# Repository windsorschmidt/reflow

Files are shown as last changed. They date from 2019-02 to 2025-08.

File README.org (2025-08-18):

* Reflow Oven Controller

"Yeah man, but it's a *dry* heat!." —PFC William L. Hudson

* About

Hardware and firmware sources for a 2-channel reflow (toaster) oven
controller.

In spite of great alternatives such as [[http://www.whizoo.com/controleo3][Controleo3]], I decided to build
my own controller for personal use. The design is intended to be
simple and self-contained. Comments and pull requests are welcome!

Some pictures of the assembled controller and completed oven retrofit
[[https://imgur.com/gallery/L4Zu2G3][are online here]].

[[reflow.png?raw=true]]

* Hardware Features

- Two triac-controlled power outputs (no external SSRs needed)
- AC line zero-crossing detection for reduced switching noise
- Temperature sensor using MAX31855 K-type thermocouple amplifier
- Compact user interface with OLED display and Cherry MX key-switches
- Data-logging output though USB and serial-to-Bluetooth module
- Tone transducer for audible alerts (e.g. reflow cycle complete)
- Mounts in a dedicated enclosure for simple wiring using IEC connectors
- [[https://en.wikipedia.org/wiki/Aliens_(film)][Aliens]] film inspired aesthetics

* Firmware Features

- Non-profiling PID routine controls triac outputs to track the active reflow profile
- Reflow profile can be viewed & edited at run-time (currently no ability to save edits)
  
[[ui.png?raw=true]]

* References

- [[https://www.allaboutcircuits.com/projects/controlling-ac-mains-with-a-microcontroller-for-fun-and-profit][This project]] was used as a basis for the triac control and zero-crossing detection circuitry
- [[https://www.reddit.com/user/rich-creamery-butter][This Reddit user]] provided [[https://imgur.com/a/sCKgO][Assembly pics]] used as a guide when converting my own oven
- The excellent [[https://github.com/olikraus/u8g2][u8g2]] library used to render user-interface graphics and text
- [[mailto:p@yusukekamiyamane.com][Yusuke Kamiyamane's]] Tempesta Seven font used in the gnuplot script
- [[http://kicad-pcb.org][KiCad]] EDA suite used for hardware schematic capture and PCB layout

* Disclaimer

This information is supplied "as is" and without warranties of any
kind, express, implied, or statutory including, but not limited to,
any implied warranty of merchantability, noninfringement or fitness
for a particular purpose and no responsibility is assumed by the
author for its use, nor for any infringements of patents or other
rights of third parties that may result from its use.

In no event will the author be liable for any loss or damage including
without limitation, indirect or consequential loss or damage, or any
loss or damage whatsoever arising from or in connection with the use
of this information.

* License

[[LICENSE.txt][MIT license]]

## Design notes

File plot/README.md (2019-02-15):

# About

The included script can be used to plot data stored in a file, as sent by the controller. Data are stored line-wise as JSON strings.

## Requirements:

- gnuplot - http://www.gnuplot.info/
- jq - https://stedolan.github.io/jq/

## Plotting

Run the script, passing the name of a log file as the argument (an example file is included):

```
$ sh make_plot.sh reflow_example.log
```

You may get a warning from gnuplot about plotting with an 'unknown' terminal -- this can be ignored. The resulting plots (with light and dark background) are generated in the current directory.

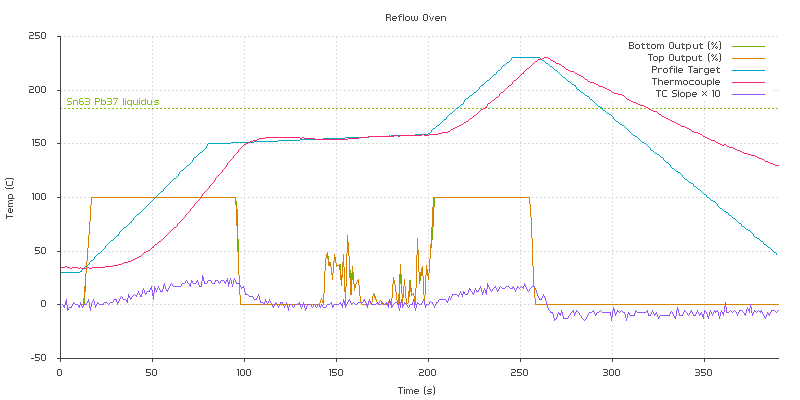
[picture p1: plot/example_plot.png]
Plot of data logged by the controller


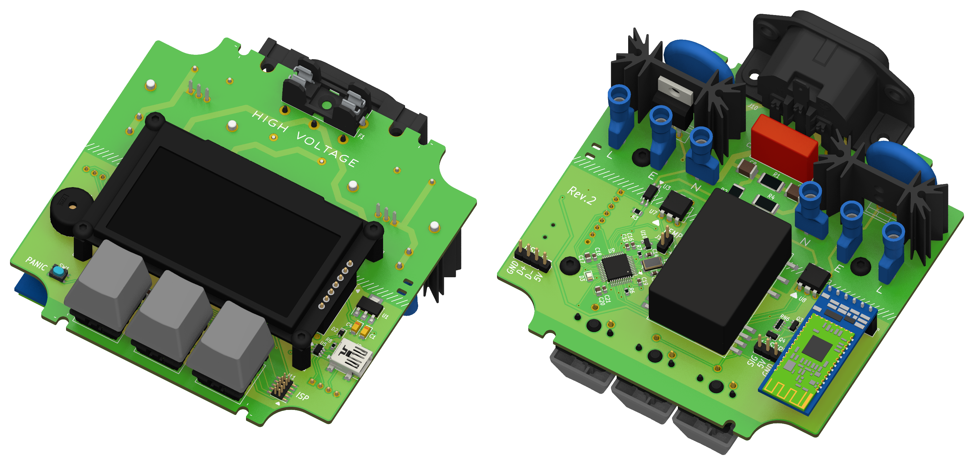
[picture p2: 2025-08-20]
reflow.png

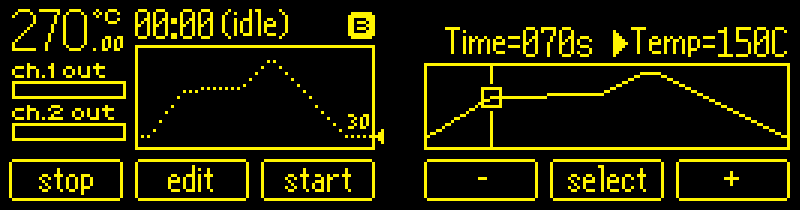
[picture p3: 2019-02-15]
ui.png

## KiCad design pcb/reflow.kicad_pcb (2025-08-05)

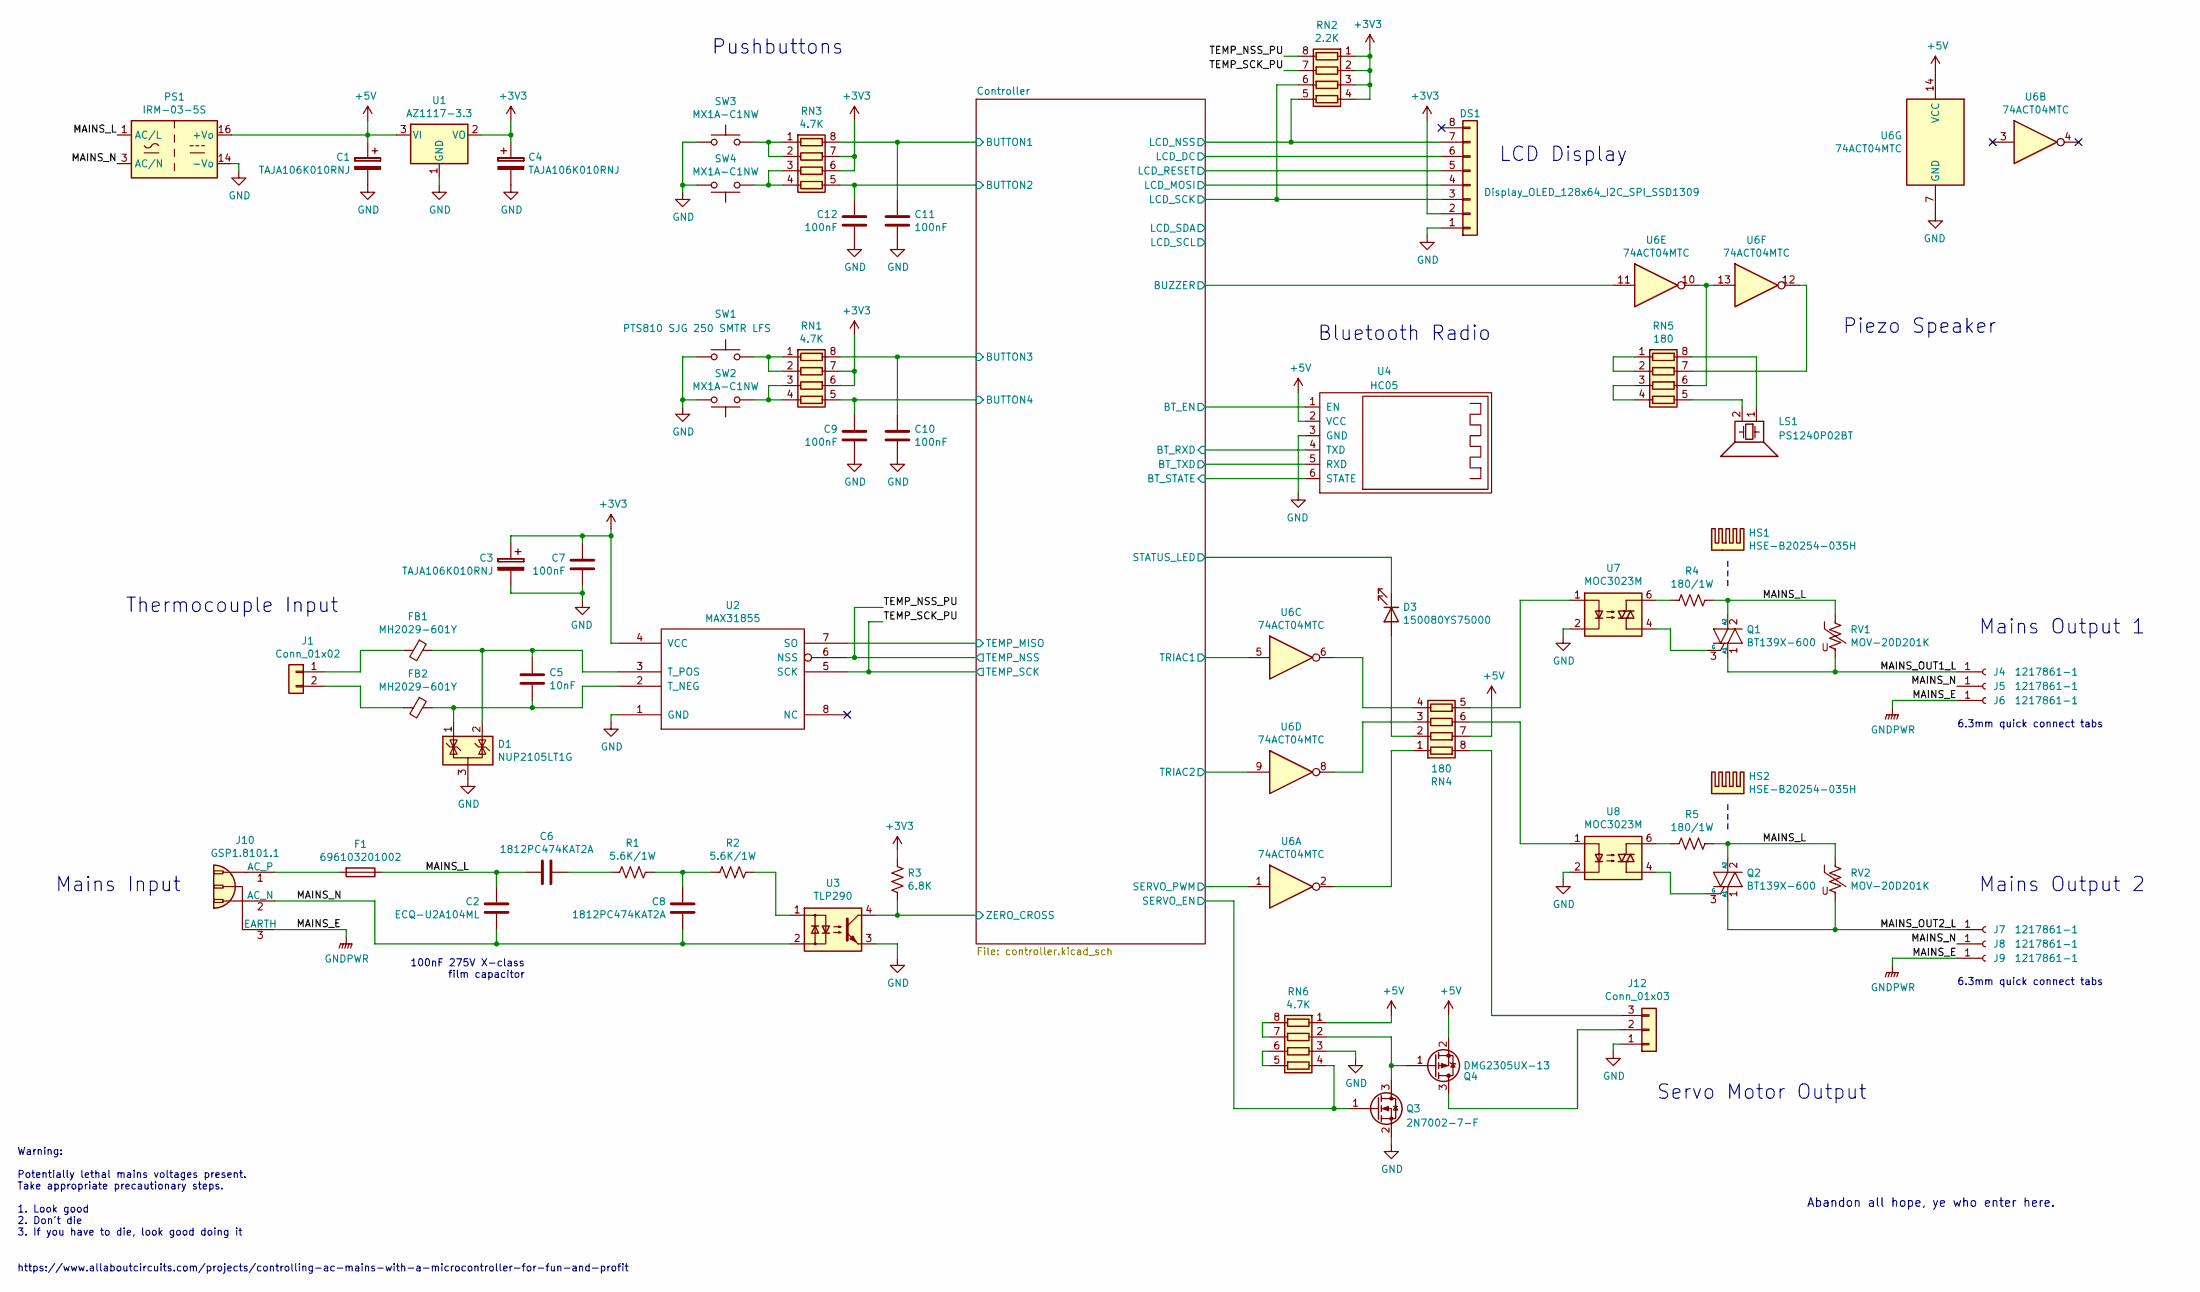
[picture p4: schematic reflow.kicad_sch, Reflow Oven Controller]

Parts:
C1, C3, C4: TAJA106K010RNJ; CP_EIA-3216-18_Kemet-A
C2: ECQ-U2A104ML; C_Rect_L18.0mm_W6.0mm_P15.00mm_FKS3_FKP3
C5: 10nF; C_0805_2012Metric
C6, C8: 1812PC474KAT2A; C_1812_4532Metric
C7, C9, C10, C11, C12: 100nF; C_0805_2012Metric
D1: NUP2105LT1G; SOT-23
D3: 150080YS75000; LED_0805_2012Metric
DS1: Display_OLED_128x64_I2C_SPI_SSD1309
F1: 696103201002; Fuseholder_Cylinder-5x20mm_Stelvio-Kontek_PTF78_Horizontal_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
FB1, FB2: MH2029-601Y; L_0805_2012Metric
HS1, HS2: HSE-B20254-035H; Heatsink_CUI_HSE-B20254-035H
J1: Conn_01x02; PinHeader_1x02_P2.54mm_Vertical
J4, J5, J6, J7, J8, J9: 1217861-1; Connector_FastOn_6.35mm
J10: GSP1.8101.1; Connector_Schurter_GSP1.8101.1
J12: Conn_01x03; PinHeader_1x03_P2.54mm_Vertical
LS1: PS1240P02BT; Buzzer_TDK_PS1240P02BT
PS1: IRM-03-5S; Converter_ACDC_MeanWell_IRM-03-xx_SMD
Q1, Q2: BT139X-600; TO-220-3_Vertical
Q3: 2N7002-7-F; SOT-23
Q4: DMG2305UX-13; SOT-23
R1, R2: 5.6K/1W; R_2512_6332Metric
R3: 6.8K; R_0805_2012Metric
R4, R5: 180/1W; R_2512_6332Metric
RN1, RN3, RN6: 4.7K; R_Array_Convex_4x0603
RN2: 2.2K; R_Array_Convex_4x0603
RN4, RN5: 180; R_Array_Convex_4x0603
RV1, RV2: MOV-20D201K; RV_Disc_D21.5mm_W4.3mm_P10mm
SW1: PTS810 SJG 250 SMTR LFS; Pushbutton_PTS810_SJx_250_SMTR_LFS
SW2, SW3, SW4: MX1A-C1NW; Switch_Cherry_MX1A_1.00u_PCB
U1: AZ1117-3.3; SOT-223
U2: MAX31855; SOIC-8_3.9x4.9mm_P1.27mm
U3: TLP290; SOP-4_4.4x2.8mm_P1.27mm
U4: HC05; Module_Bluetooth_HC05
U6: 74ACT04MTC; TSSOP-14_4.4x5mm_P0.65mm
U7, U8: MOC3023M; DIP-6_W7.62mm

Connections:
+3V3: C3.1, C4.1, C7.1, DS1.2, R3.2, RN1.6 (R3.2), RN1.7 (R2.2), RN2.1 (R1.1), RN2.2 (R2.1), RN2.3 (R3.1), RN2.4 (R4.1), RN3.6 (R3.2), RN3.7 (R2.2), U1.2 (VO), U2.4 (VCC); also elsewhere on the board
+5V: C1.1, PS1.16 (+Vo), Q4.2 (S), RN4.7 (R2.2), RN6.1 (R1.1), U1.3 (VI), U4.2 (VCC), U6.14 (VCC); also elsewhere on the board
/Controller/BT_EN: U4.1 (EN); also elsewhere on the board
/Controller/BT_RXD: U4.4 (TXD); also elsewhere on the board
/Controller/BT_STATE: U4.6 (STATE); also elsewhere on the board
/Controller/BT_TXD: U4.5 (RXD); also elsewhere on the board
/Controller/BUTTON1: C11.1, RN3.8 (R1.2); also elsewhere on the board
/Controller/BUTTON2: C12.2, RN3.5 (R4.2); also elsewhere on the board
/Controller/BUTTON3: C10.1, RN1.8 (R1.2); also elsewhere on the board
/Controller/BUTTON4: C9.2, RN1.5 (R4.2); also elsewhere on the board
/Controller/BUZZER: U6.11; also elsewhere on the board
/Controller/LCD_DC: DS1.6; also elsewhere on the board
/Controller/LCD_MOSI: DS1.4; also elsewhere on the board
/Controller/LCD_NSS: DS1.7, RN2.5 (R4.2); also elsewhere on the board
/Controller/LCD_RESET: DS1.5; also elsewhere on the board
/Controller/LCD_SCK: DS1.3, RN2.6 (R3.2); also elsewhere on the board
/Controller/SERVO_EN: Q3.1 (G), RN6.4 (R4.1); also elsewhere on the board
/Controller/SERVO_PWM: U6.1; also elsewhere on the board
/Controller/STATUS_LED: D3.1 (K); also elsewhere on the board
/Controller/TEMP_MISO: U2.7 (SO); also elsewhere on the board
/Controller/TRIAC1: U6.5; also elsewhere on the board
/Controller/TRIAC2: U6.9; also elsewhere on the board
/Controller/ZERO_CROSS: R3.1, U3.4; also elsewhere on the board
/MAINS_L: C2.1, C6.2, F1.1, PS1.1 (AC/L), Q1.2 (A2), Q2.2 (A2), R4.1, R5.1, RV1.1, RV2.1
/MAINS_N: C2.2, C8.1, J5.1, J8.1, J10.2 (AC_N), PS1.3 (AC/N), U3.2
/MAINS_OUT1_L: J4.1, Q1.1 (A1), RV1.2
/MAINS_OUT2_L: J7.1, Q2.1 (A1), RV2.2
/TEMP_NSS_PU: RN2.8 (R1.2), U2.6 (NSS); also elsewhere on the board
/TEMP_SCK_PU: RN2.7 (R2.2), U2.5 (SCK); also elsewhere on the board
GND: C1.2, C3.2, C4.2, C7.2, C9.1, C10.2, C11.2, C12.1, D1.3 (A), DS1.1, J12.1, PS1.14 (-Vo), Q3.2 (S), RN6.3 (R3.1), SW1.1, SW2.1, SW3.1, SW4.1, U1.1 (GND), U2.1 (GND), U3.3, U4.3 (GND), U6.7 (GND), U7.2, U8.2; also elsewhere on the board
GNDPWR: J6.1, J9.1, J10.3 (EARTH)
unnamed: C5.1, D1.2 (K), FB1.1, U2.3 (T_POS)
unnamed: C5.2, D1.1 (K), FB2.1, U2.2 (T_NEG)
unnamed: C6.1, R1.2
unnamed: C8.2, R1.1, R2.2
unnamed: D3.2 (A), RN4.2 (R2.1)
unnamed: F1.2, J10.1 (AC_P)
unnamed: FB1.2, J1.1
unnamed: FB2.2, J1.2
unnamed: J12.2, Q4.3 (D)
unnamed: J12.3, RN4.8 (R1.2)
unnamed: LS1.1, RN5.8 (R1.2)
unnamed: LS1.2, RN5.5 (R4.2)
unnamed: Q1.3 (G), U7.4
unnamed: Q2.3 (G), U8.4
unnamed: Q3.3 (D), Q4.1 (G), RN6.2 (R2.1)
unnamed: R2.1, U3.1
unnamed: R4.2, U7.6
unnamed: R5.2, U8.6
unnamed: RN1.1 (R1.1), RN1.2 (R2.1), SW1.2
unnamed: RN1.3 (R3.1), RN1.4 (R4.1), SW2.2
unnamed: RN3.1 (R1.1), RN3.2 (R2.1), SW3.2
unnamed: RN3.3 (R3.1), RN3.4 (R4.1), SW4.2
unnamed: RN4.1 (R1.1), U6.2
unnamed: RN4.3 (R3.1), U6.8
unnamed: RN4.4 (R4.1), U6.6
unnamed: RN4.5 (R4.2), U7.1
unnamed: RN4.6 (R3.2), U8.1
unnamed: RN5.1 (R1.1), RN5.2 (R2.1)
unnamed: RN5.3 (R3.1), RN5.4 (R4.1)
unnamed: RN5.6 (R3.2), U6.10, U6.13
unnamed: RN5.7 (R2.2), U6.12
unnamed: RN6.5 (R4.2), RN6.6 (R3.2)
unnamed: RN6.7 (R2.2), RN6.8 (R1.2)

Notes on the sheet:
6.3mm quick connect tabs
Pushbuttons
Bluetooth Radio
Mains Input
Abandon all hope, ye who enter here.
Mains Output 2
100nF 275V X-class film capacitor
Thermocouple Input
https://www.allaboutcircuits.com/projects/controlling-ac-mains-with-a-microcontroller-for-fun-and-profit
LCD Display
Warning: Potentially lethal mains voltages present. Take appropriate precautionary steps. 1. Look good 2. Don't die 3. If you have to die, look good doing it
Mains Output 1
Servo Motor Output
Piezo Speaker

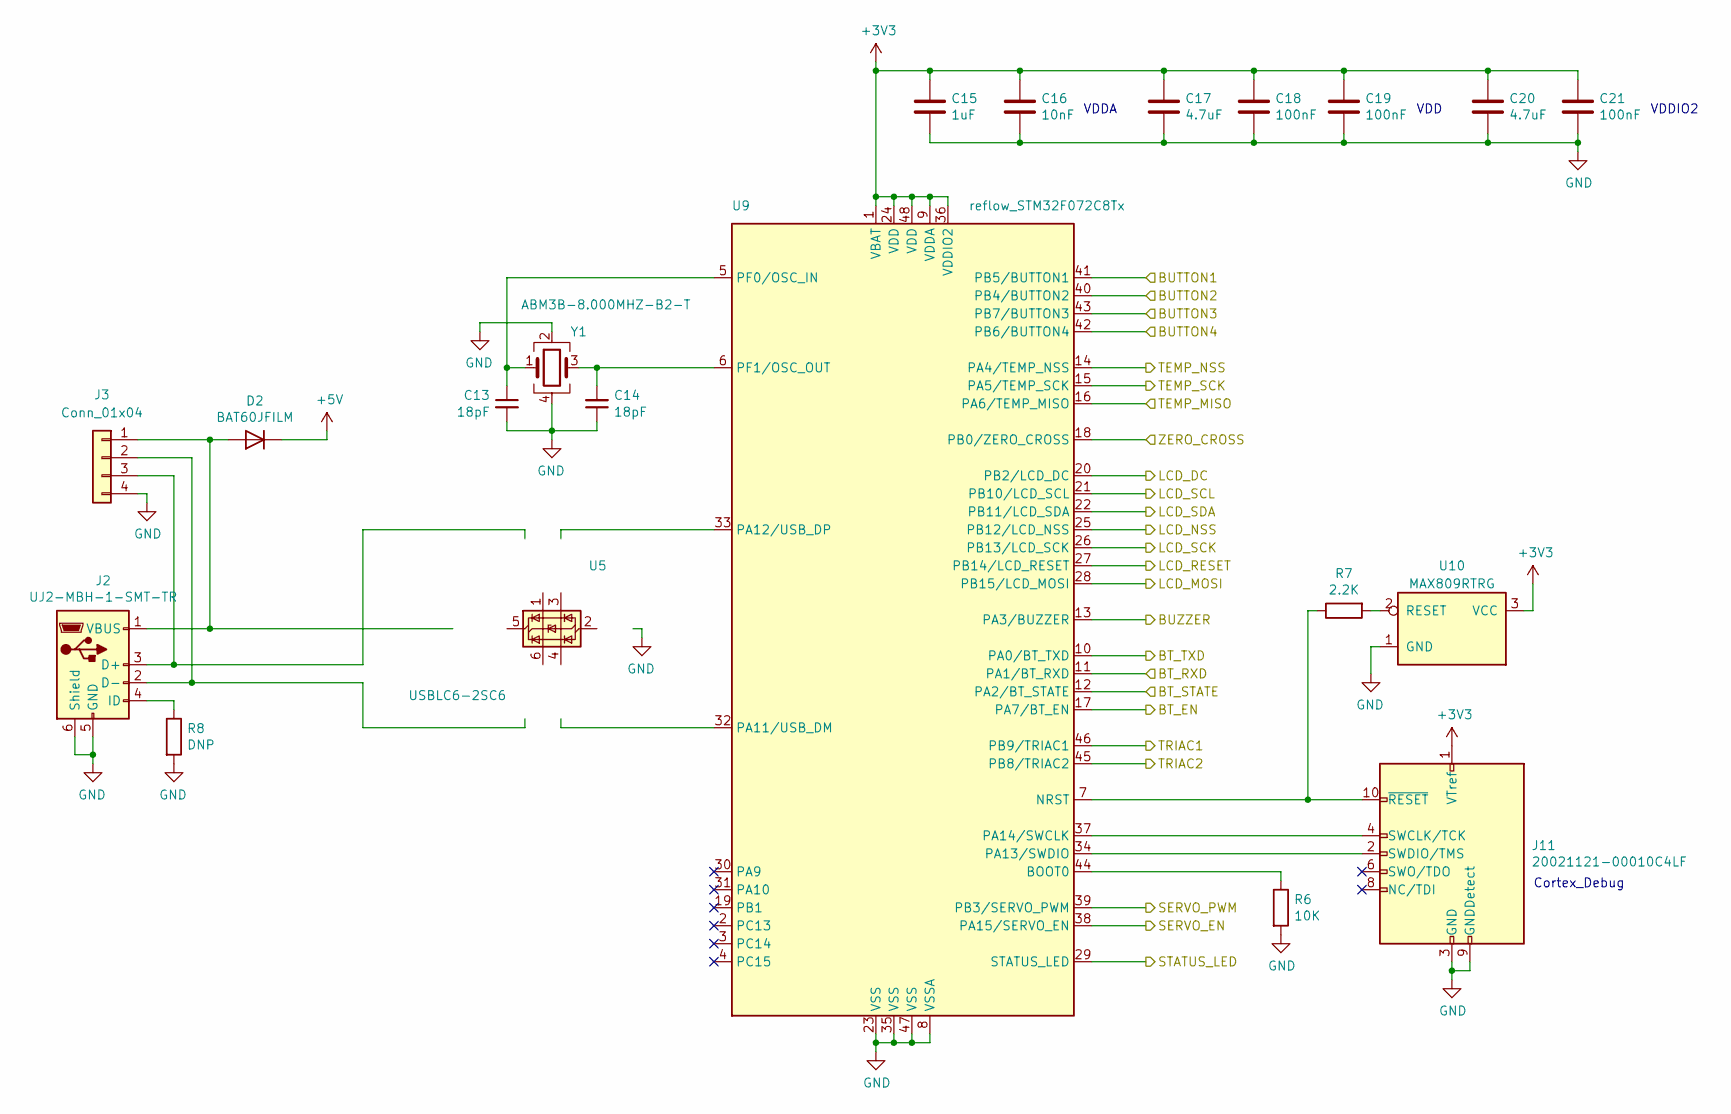
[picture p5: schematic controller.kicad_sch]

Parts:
C13, C14: 18pF; C_0603_1608Metric
C15: 1uF; C_0603_1608Metric
C16: 10nF; C_0603_1608Metric
C17, C20: 4.7uF; C_0805_2012Metric
C18, C19, C21: 100nF; C_0603_1608Metric
D2: BAT60JFILM; D_SOD-323
J2: UJ2-MBH-1-SMT-TR; USB_Mini-B_Lumberg_2486_01_Horizontal
J3: Conn_01x04; PinHeader_1x04_P2.54mm_Vertical
J11: 20021121-00010C4LF; PinHeader_2x05_P1.27mm_Vertical_SMD
R6: 10K; R_0603_1608Metric
R7: 2.2K; R_0603_1608Metric
R8: DNP; R_0603_1608Metric
U5: USBLC6-2SC6; SOT-23-6
U9: reflow_STM32F072C8Tx; LQFP-48_7x7mm_P0.5mm
U10: MAX809RTRG; SOT-23
Y1: ABM3B-8.000MHZ-B2-T; Crystal_Abracon_ABM3B-8.000MHZ-B2-T

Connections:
+3V3: C15.1, C16.2, C17.2, C18.1, C19.1, C20.2, C21.1, J11.1 (VTref), U9.1 (VBAT), U9.9 (VDDA), U9.24 (VDD), U9.36 (VDDIO2), U9.48 (VDD), U10.3 (VCC); also elsewhere on the board
+5V: D2.1 (K); also elsewhere on the board
/Controller/BT_EN: U9.17 (PA7/BT_EN); also elsewhere on the board
/Controller/BT_RXD: U9.11 (PA1/BT_RXD); also elsewhere on the board
/Controller/BT_STATE: U9.12 (PA2/BT_STATE); also elsewhere on the board
/Controller/BT_TXD: U9.10 (PA0/BT_TXD); also elsewhere on the board
/Controller/BUTTON1: U9.41 (PB5/BUTTON1); also elsewhere on the board
/Controller/BUTTON2: U9.40 (PB4/BUTTON2); also elsewhere on the board
/Controller/BUTTON3: U9.43 (PB7/BUTTON3); also elsewhere on the board
/Controller/BUTTON4: U9.42 (PB6/BUTTON4); also elsewhere on the board
/Controller/BUZZER: U9.13 (PA3/BUZZER); also elsewhere on the board
/Controller/LCD_DC: U9.20 (PB2/LCD_DC); also elsewhere on the board
/Controller/LCD_MOSI: U9.28 (PB15/LCD_MOSI); also elsewhere on the board
/Controller/LCD_NSS: U9.25 (PB12/LCD_NSS); also elsewhere on the board
/Controller/LCD_RESET: U9.27 (PB14/LCD_RESET); also elsewhere on the board
/Controller/LCD_SCK: U9.26 (PB13/LCD_SCK); also elsewhere on the board
/Controller/SERVO_EN: U9.38 (PA15/SERVO_EN); also elsewhere on the board
/Controller/SERVO_PWM: U9.39 (PB3/SERVO_PWM); also elsewhere on the board
/Controller/STATUS_LED: U9.29 (STATUS_LED); also elsewhere on the board
/Controller/TEMP_MISO: U9.16 (PA6/TEMP_MISO); also elsewhere on the board
/Controller/TRIAC1: U9.46 (PB9/TRIAC1); also elsewhere on the board
/Controller/TRIAC2: U9.45 (PB8/TRIAC2); also elsewhere on the board
/Controller/ZERO_CROSS: U9.18 (PB0/ZERO_CROSS); also elsewhere on the board
/TEMP_NSS_PU: U9.14 (PA4/TEMP_NSS); also elsewhere on the board
/TEMP_SCK_PU: U9.15 (PA5/TEMP_SCK); also elsewhere on the board
GND: C13.2, C14.1, C15.2, C16.1, C17.1, C18.2, C19.2, C20.1, C21.2, J2.5 (GND), J2.6 (Shield), J3.4, J11.3 (GND), J11.5 (GND), J11.9 (GNDDetect), R6.2, R8.2, U5.2 (GND), U9.8 (VSSA), U9.23 (VSS), U9.35 (VSS), U9.47 (VSS), U10.1 (GND), Y1.2, Y1.4; also elsewhere on the board
unnamed: C13.1, U9.5 (PF0/OSC_IN), Y1.1
unnamed: C14.2, U9.6 (PF1/OSC_OUT), Y1.3
unnamed: J2.4 (ID), R8.1
unnamed: J11.2 (SWDIO/TMS), U9.34 (PA13/SWDIO)
unnamed: J11.4 (SWCLK/TCK), U9.37 (PA14/SWCLK)
unnamed: J11.10 (~RESET), R7.1, U9.7 (NRST)
unnamed: R6.1, U9.44 (BOOT0)
unnamed: R7.2, U10.2 (RESET)
unnamed: U5.1 (I/O1), U9.33 (PA12/USB_DP)
unnamed: U5.3 (I/O2), U9.32 (PA11/USB_DM)

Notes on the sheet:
VDDIO2
VDD
VDDA
Cortex_Debug

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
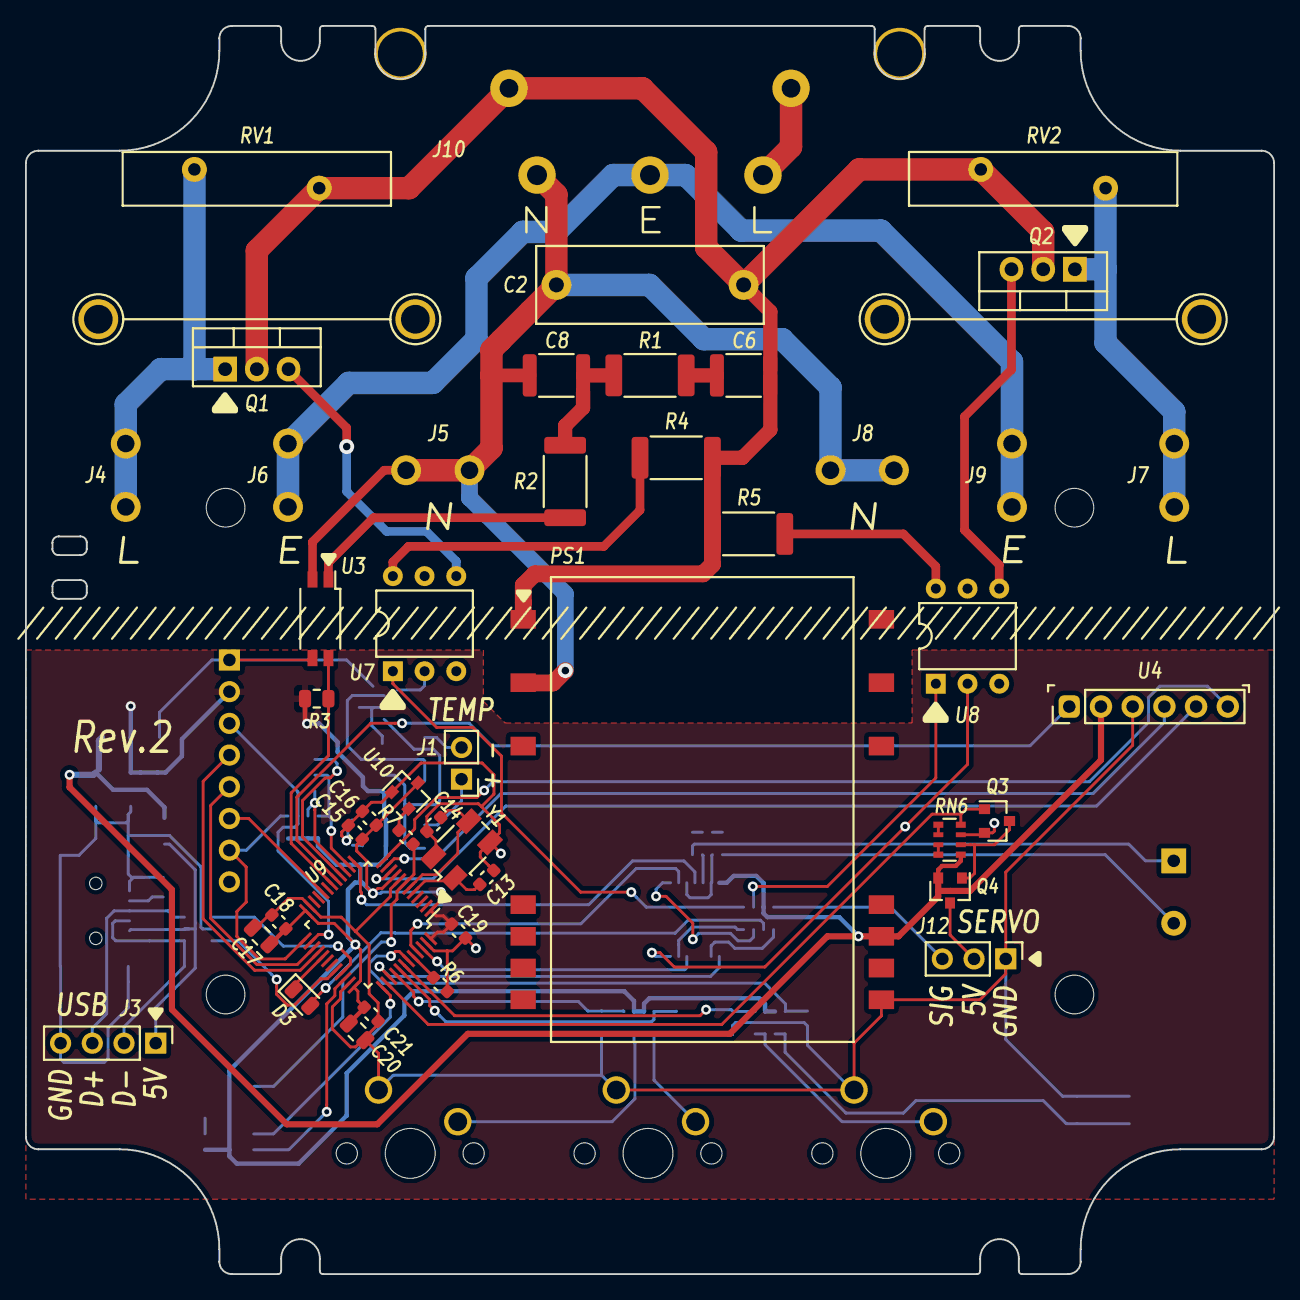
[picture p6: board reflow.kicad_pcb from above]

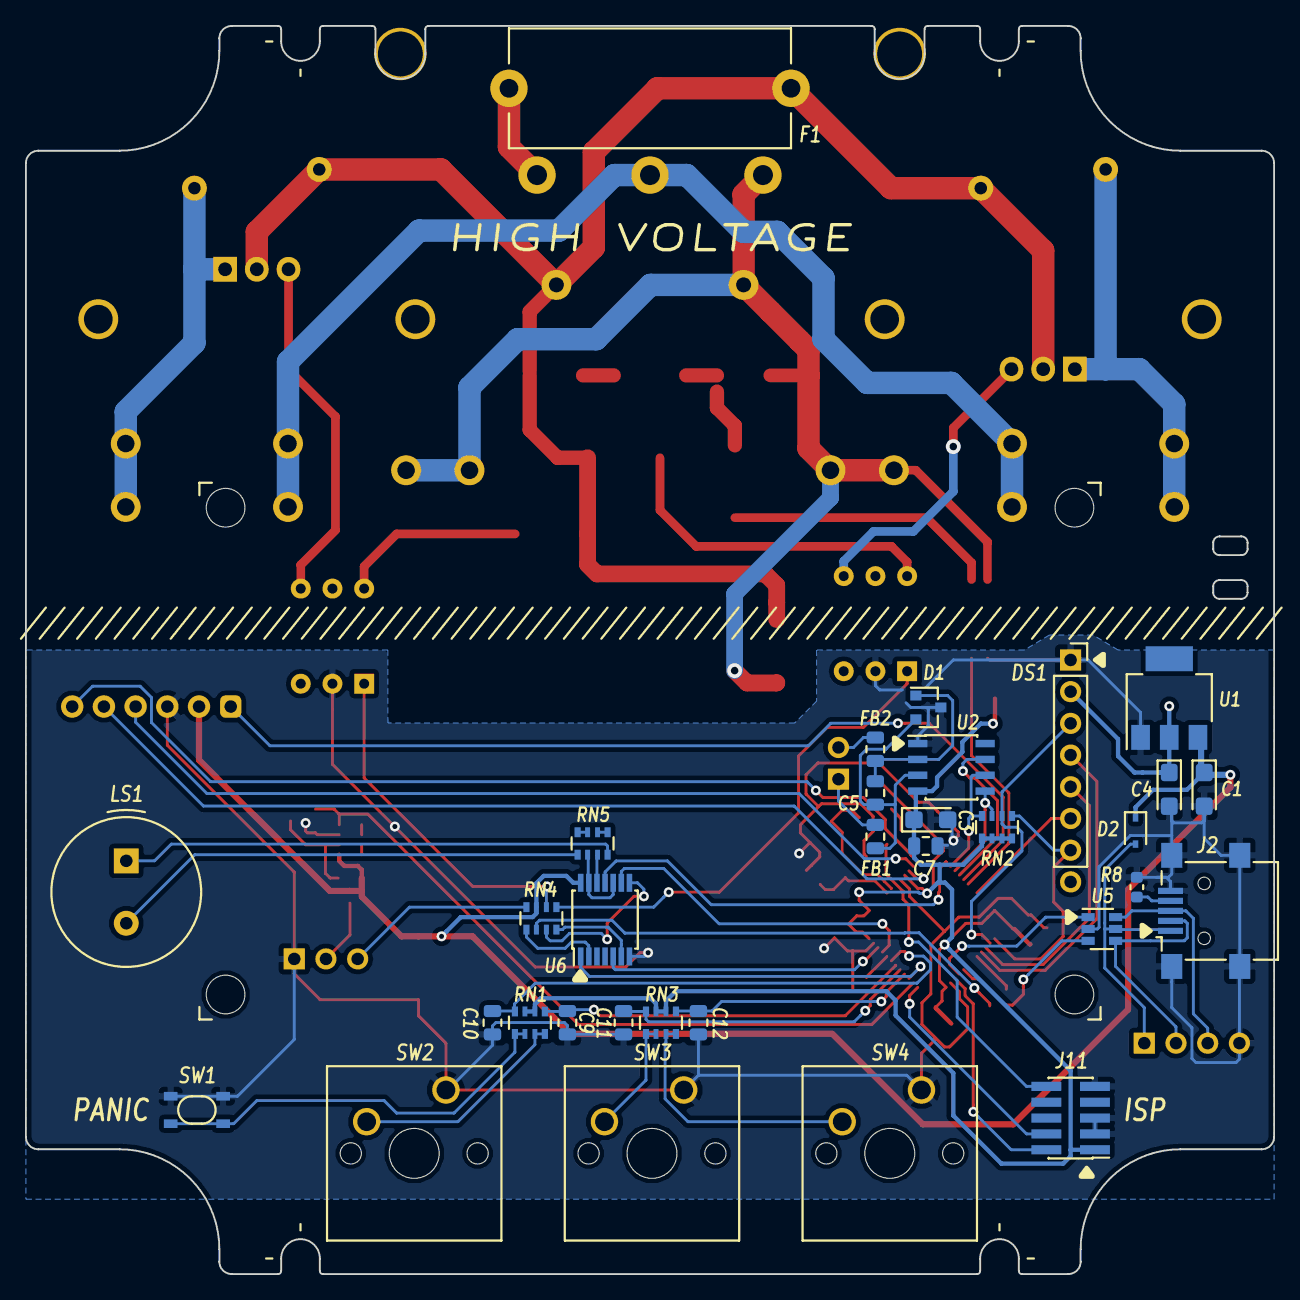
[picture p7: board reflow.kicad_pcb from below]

Board: 2 copper layers, 100.0 x 100.0 mm, 95 parts (38 on the bottom side), 77 nets.

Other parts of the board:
G1, G2, G4, G5: Artwork_Pin_Marker
G3, G6, G7, G8, G9, G10, G11, G12, G13, G14, G15: Artwork_Pin_Marker_Small
MNT**: Mount_Zip_Tie; MOUNT_ZIP_TIE_2X

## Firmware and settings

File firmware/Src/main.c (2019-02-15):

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

/* Includes ------------------------------------------------------------------*/
#include "main.h"
#include "cmsis_os.h"
#include "usb_device.h"

/* USER CODE BEGIN Includes */
#include "app.h"
#include "timer.h"
/* USER CODE END Includes */

SPI_HandleTypeDef hspi1;
SPI_HandleTypeDef hspi2;

TIM_HandleTypeDef htim2;
TIM_HandleTypeDef htim3;
TIM_HandleTypeDef htim14;
TIM_HandleTypeDef htim15;
TIM_HandleTypeDef htim16;
TIM_HandleTypeDef htim17;

UART_HandleTypeDef huart4;

osThreadId defaultTaskHandle;
/* USER CODE BEGIN PV */

/* USER CODE END PV */

void SystemClock_Config(void);
static void MX_GPIO_Init(void);
static void MX_SPI1_Init(void);
static void MX_SPI2_Init(void);
static void MX_USART4_UART_Init(void);
static void MX_TIM14_Init(void);
static void MX_TIM2_Init(void);
static void MX_TIM15_Init(void);
static void MX_TIM16_Init(void);
static void MX_TIM17_Init(void);
static void MX_TIM3_Init(void);
void StartDefaultTask(void const * argument);

/* USER CODE BEGIN PFP */

/* USER CODE END PFP */

/**
  * @brief  The application entry point.
  * @retval int
  */
int main(void)
{
  /* MCU Configuration--------------------------------------------------------*/

  /* Reset of all peripherals, Initializes the Flash interface and the Systick. */
  HAL_Init();

  /* Configure the system clock */
  SystemClock_Config();

  /* Initialize all configured peripherals */
  MX_GPIO_Init();
  MX_SPI1_Init();
  MX_SPI2_Init();
  MX_USART4_UART_Init();
  MX_TIM14_Init();
  MX_TIM2_Init();
  MX_TIM15_Init();
  MX_TIM16_Init();
  MX_TIM17_Init();
  MX_TIM3_Init();
  /* USER CODE BEGIN 2 */

  app_init();
  
  /* USER CODE END 2 */

  /* USER CODE BEGIN RTOS_MUTEX */
  /* add mutexes, ... */
  /* USER CODE END RTOS_MUTEX */

  /* USER CODE BEGIN RTOS_SEMAPHORES */
  /* add semaphores, ... */
  /* USER CODE END RTOS_SEMAPHORES */

  /* USER CODE BEGIN RTOS_TIMERS */
  /* start timers, add new ones, ... */
  /* USER CODE END RTOS_TIMERS */

  /* Create the thread(s) */
  /* definition and creation of defaultTask */
  osThreadDef(defaultTask, StartDefaultTask, osPriorityNormal, 0, 128);
  defaultTaskHandle = osThreadCreate(osThread(defaultTask), NULL);

  /* USER CODE BEGIN RTOS_THREADS */
  /* add threads, ... */
  /* USER CODE END RTOS_THREADS */

  /* USER CODE BEGIN RTOS_QUEUES */
  /* add queues, ... */
  /* USER CODE END RTOS_QUEUES */
 

  /* Start scheduler */
  osKernelStart();
  
  /* We should never get here as control is now taken by the scheduler */

  /* Infinite loop */
}

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
/* USER CODE BEGIN Header_StartDefaultTask */
/**
  * @brief  Function implementing the defaultTask thread.
  * @param  argument: Not used 
  * @retval None
  */
/* USER CODE END Header_StartDefaultTask */
void StartDefaultTask(void const * argument)
{
  /* init code for USB_DEVICE */
  MX_USB_DEVICE_Init();

  /* USER CODE BEGIN 5 */
  /* Infinite loop */
  (void) argument;
    
  for(;;)
  {
    osDelay(1);
  }
  /* USER CODE END 5 */ 
}

/**
  * @brief  Period elapsed callback in non blocking mode
  * @note   This function is called  when TIM1 interrupt took place, inside
  * HAL_TIM_IRQHandler(). It makes a direct call to HAL_IncTick() to increment
  * a global variable "uwTick" used as application time base.
  * @param  htim : TIM handle
  * @retval None
  */
void HAL_TIM_PeriodElapsedCallback(TIM_HandleTypeDef *htim)
{
  if (htim->Instance == TIM1) {
    HAL_IncTick();
  }
  /* USER CODE BEGIN Callback 1 */
  if (htim->Instance == TIM14) {
      timer_tick_1hz();
  }
  
  if (htim->Instance == TIM3) {
      timer_tick_speaker();
  }
  /* USER CODE END Callback 1 */
}

/**
  * @brief  This function is executed in case of error occurrence.
  * @retval None
  */
void Error_Handler(void)
{
  /* USER CODE BEGIN Error_Handler_Debug */
  /* User can add his own implementation to report the HAL error return state */
  while(1)
  {
  }
  /* USER CODE END Error_Handler_Debug */
}

#ifdef  USE_FULL_ASSERT
/**
  * @brief  Reports the name of the source file and the source line number
  *         where the assert_param error has occurred.
  * @param  file: pointer to the source file name
  * @param  line: assert_param error line source number
  * @retval None
  */
void assert_failed(char *file, uint32_t line)
{ 
  /* USER CODE BEGIN 6 */
  /* User can add his own implementation to report the file name and line number,
     tex: printf("Wrong parameters value: file %s on line %d\r\n", file, line) */
  /* USER CODE END 6 */
}
#endif /* USE_FULL_ASSERT */

/************************ (C) COPYRIGHT STMicroelectronics *****END OF FILE****/

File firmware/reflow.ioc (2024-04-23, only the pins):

Mcu.UserName=STM32F072C8Tx
PA0.Signal=USART4_TX
PA1.Signal=USART4_RX
PA11.Signal=USB_DM
PA12.Signal=USB_DP
PA13.GPIO_Label=SWDIO
PA13.Signal=SYS_SWDIO
PA14.GPIO_Label=SWCLK
PA14.Signal=SYS_SWCLK
PA15.GPIO_Label=SERVO_EN
PA15.Signal=GPIO_Output
PA2.GPIO_Label=BT_STATE
PA2.Signal=GPXTI2
PA3.GPIO_Label=BUZZER
PA3.Signal=S_TIM15_CH2
PA4.GPIO_Label=TEMP_NSS
PA4.Signal=SPI1_NSS
PA5.GPIO_Label=TEMP_SCK
PA5.Signal=SPI1_SCK
PA6.GPIO_Label=TEMP_MISO
PA6.Signal=SPI1_MISO
PA7.GPIO_Label=BT_EN
PA7.Signal=GPIO_Output
PA8.GPIO_Label=STATUS_LED
PA8.Signal=GPIO_Output
PB0.GPIO_Label=ZERO_CROSS
PB0.Signal=GPXTI0
PB12.GPIO_Label=OLED_NSS
PB12.Signal=SPI2_NSS
PB13.GPIO_Label=OLED_SCK
PB13.Signal=SPI2_SCK
PB14.GPIO_Label=OLED_RESET
PB14.Signal=GPIO_Output
PB15.GPIO_Label=OLED_MOSI
PB15.Signal=SPI2_MOSI
PB2.GPIO_Label=OLED_DC
PB2.Signal=GPIO_Output
PB3.GPIO_Label=FAN_TACH
PB3.Signal=GPIO_Output
PB4.GPIO_Label=BUTTON_NEXT
PB4.Signal=GPXTI4
PB5.GPIO_Label=BUTTON_SET
PB5.Signal=GPXTI5
PB6.GPIO_Label=BUTTON_PREV
PB6.Signal=GPXTI6
PB7.GPIO_Label=BUTTON_PANIC
PB7.Signal=GPXTI7
PB8.GPIO_Label=TRIAC2
PB8.Signal=S_TIM16_CH1
PB9.GPIO_Label=TRIAC1
PB9.Signal=S_TIM17_CH1
PF0-OSC_IN.Signal=RCC_OSC_IN
PF1-OSC_OUT.Signal=RCC_OSC_OUT

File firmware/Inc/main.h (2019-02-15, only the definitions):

#define BT_STATE_Pin GPIO_PIN_2
#define BT_STATE_GPIO_Port GPIOA
#define BT_STATE_EXTI_IRQn EXTI2_3_IRQn
#define BUZZER_Pin GPIO_PIN_3
#define BUZZER_GPIO_Port GPIOA
#define TEMP_NSS_Pin GPIO_PIN_4
#define TEMP_NSS_GPIO_Port GPIOA
#define TEMP_SCK_Pin GPIO_PIN_5
#define TEMP_SCK_GPIO_Port GPIOA
#define TEMP_MISO_Pin GPIO_PIN_6
#define TEMP_MISO_GPIO_Port GPIOA
#define BT_EN_Pin GPIO_PIN_7
#define BT_EN_GPIO_Port GPIOA
#define ZERO_CROSS_Pin GPIO_PIN_0
#define ZERO_CROSS_GPIO_Port GPIOB
#define ZERO_CROSS_EXTI_IRQn EXTI0_1_IRQn
#define OLED_DC_Pin GPIO_PIN_2
#define OLED_DC_GPIO_Port GPIOB
#define OLED_NSS_Pin GPIO_PIN_12
#define OLED_NSS_GPIO_Port GPIOB
#define OLED_SCK_Pin GPIO_PIN_13
#define OLED_SCK_GPIO_Port GPIOB
#define OLED_RESET_Pin GPIO_PIN_14
#define OLED_RESET_GPIO_Port GPIOB
#define OLED_MOSI_Pin GPIO_PIN_15
#define OLED_MOSI_GPIO_Port GPIOB
#define STATUS_LED_Pin GPIO_PIN_8
#define STATUS_LED_GPIO_Port GPIOA
#define SWDIO_Pin GPIO_PIN_13
#define SWDIO_GPIO_Port GPIOA
#define SWCLK_Pin GPIO_PIN_14
#define SWCLK_GPIO_Port GPIOA
#define SERVO_EN_Pin GPIO_PIN_15
#define SERVO_EN_GPIO_Port GPIOA
#define FAN_TACH_Pin GPIO_PIN_3
#define FAN_TACH_GPIO_Port GPIOB
#define BUTTON_NEXT_Pin GPIO_PIN_4
#define BUTTON_NEXT_GPIO_Port GPIOB
#define BUTTON_NEXT_EXTI_IRQn EXTI4_15_IRQn
#define BUTTON_SET_Pin GPIO_PIN_5
#define BUTTON_SET_GPIO_Port GPIOB
#define BUTTON_SET_EXTI_IRQn EXTI4_15_IRQn
#define BUTTON_PREV_Pin GPIO_PIN_6
#define BUTTON_PREV_GPIO_Port GPIOB
#define BUTTON_PREV_EXTI_IRQn EXTI4_15_IRQn
#define BUTTON_PANIC_Pin GPIO_PIN_7
#define BUTTON_PANIC_GPIO_Port GPIOB
#define BUTTON_PANIC_EXTI_IRQn EXTI4_15_IRQn
#define TRIAC2_Pin GPIO_PIN_8
#define TRIAC2_GPIO_Port GPIOB
#define TRIAC1_Pin GPIO_PIN_9
#define TRIAC1_GPIO_Port GPIOB

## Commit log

2019-02-15 add link to oven and PCB images
2024-04-23 update pcb image
2024-04-23 misc edits
    [reflow.kicad_pcb]
2025-08-05 update pcb for kicad 9
    [controller.kicad_sch, controller.sch, reflow.kicad_pcb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]
2025-08-20 remove pcb images

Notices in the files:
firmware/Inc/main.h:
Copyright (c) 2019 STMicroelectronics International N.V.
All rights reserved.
